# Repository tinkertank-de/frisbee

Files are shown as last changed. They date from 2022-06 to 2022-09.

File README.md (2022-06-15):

# Tinkertank's Frisbee - the sustainable Microcontroller

The Frisbee is your perfect tool to make new inventions out of e-waste, old toys and everyday objects.

front

The Frisbee is a microcontroller that can be plugged into any computer via USB and is recognized as a keyboard. Thus, similar to the Makey Makey ( https://makeymakey.com/ ), all conductive objects can be used to close circuits and trigger keystrokes. So a fork stuck in an apple becomes a space bar, or a high-five with your best friend becomes an arrow key.
If you still haven't had enough, you can turn the frisbee upside down to the dark side and dive deeper into the rabbit hole of makers and coders. On the backside and with the help of a block-based programming platform like OpenRoberta it is easy to run every actuator and sensor you find in the electronic waste to make your idea reality.

darkside
<br>*dark side of the ~~moon~~ frisbee*

# another microcontroller?

yes, why not.
it's plug and play like a [Makey Makey](https://makeymakey.com/), it's accessible with alligator clamps and easy to reprogram like the [Micro:bit](https://microbit.org//), it's cheap like an [Arduino Nano](https://store.arduino.cc/collections/most-popular/products/arduino-nano-every-with-headers) and it's capable of running micropython for super fast and compile-free programming.
Aaaaand it's got a super sweet RG-Bee-LED shining through the pcb for instant feedback. (reverse mounted neopixel LED)

# comparison sheet
| | Arduino Uno | Makey Makey | Micro:Bit | Calliope | Frisbee 2.0 |
| --- | --- | --- | --- | --- | --- |
| Image | | | | | |
| forked from | | Pro Micro /<br>Arduino Leonardo | | Micro:Bit | Raspberry Pi Pico |
| | | | | | |
| hardware connectors | jumper wires | alligator clips | alligator clips (limited) | alligator clips | alligator clips |
| cpu | ATmega328 (8-bit) | Atmel 32U4 | ARM Cortex-M0 (Nordic nRF51822) mit 32-Bit | ARM Cortex-M0 (Nordic nRF51822) mit 32-Bit | dual-core Arm Cortex-M0+ |
| native node based programming | NO | NO | YES | YES | YES |
| Bluetooth | NO | NO | YES | YES | NO |
| Wifi | NO | NO | NO | NO | NO |
| additional periphery | LED | LED | Lagesensor, Buttons, LED Matrix, Kompass, RGB-LED, Temperatur, Lautsprecher, Mikrofon | Lagesensor, Buttons, LED Matrix, Kompass, RGB-LED, Temperatur, Lautsprecher, Mikrofon | LED |
| plug and play input device | NO | YES | NO | NO | YES |
| made in | china | china | ? | ? | D |
| hareware cost | 23,50 € | 55,00 € | 29,00 € | 40,00 € | 15,00 € |

# fair trade & regional
We try to produce the frisbee boards as sustainable as possible and under fair working conditions in germany.
We are experimenting with different technologies like Paper-PCBs or printing with conductive paint on wood as an eco-friendly alternative to epoxy-based PCBs.

# open source
The Frisbee, like its core, the Pi Pico, is completely open source and can be further developed, modified and used by all users under the Creative Commons 4.0 license.

# about
Tinkertank is a stationary and mobile makerspace based in Ludwigsburg, Germany, empowering kids and adults to the creative use of technology.
www.tinkertank.de

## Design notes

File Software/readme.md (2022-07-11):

# 1. Install Circuitpython

- Plug in your Frisbee device while holding den **BOOTSEL** Button *(it should show up as RPI-RP2)*
- copy **"adafruit-circuitpython-raspberry_pi_pico-de_DE-7.3.1.uf2"** to your device
- wait until it restarts *(it should show up as CIRCUITPY)*

# 2. copy code

- copy **code.py** and **lib folder** onto CIRCUITPY *(replace code.py)*

# 3. Test code

- got to **[keyboard-test.space](https://keyboard-test.space/)** *(or similar)* to test all functions

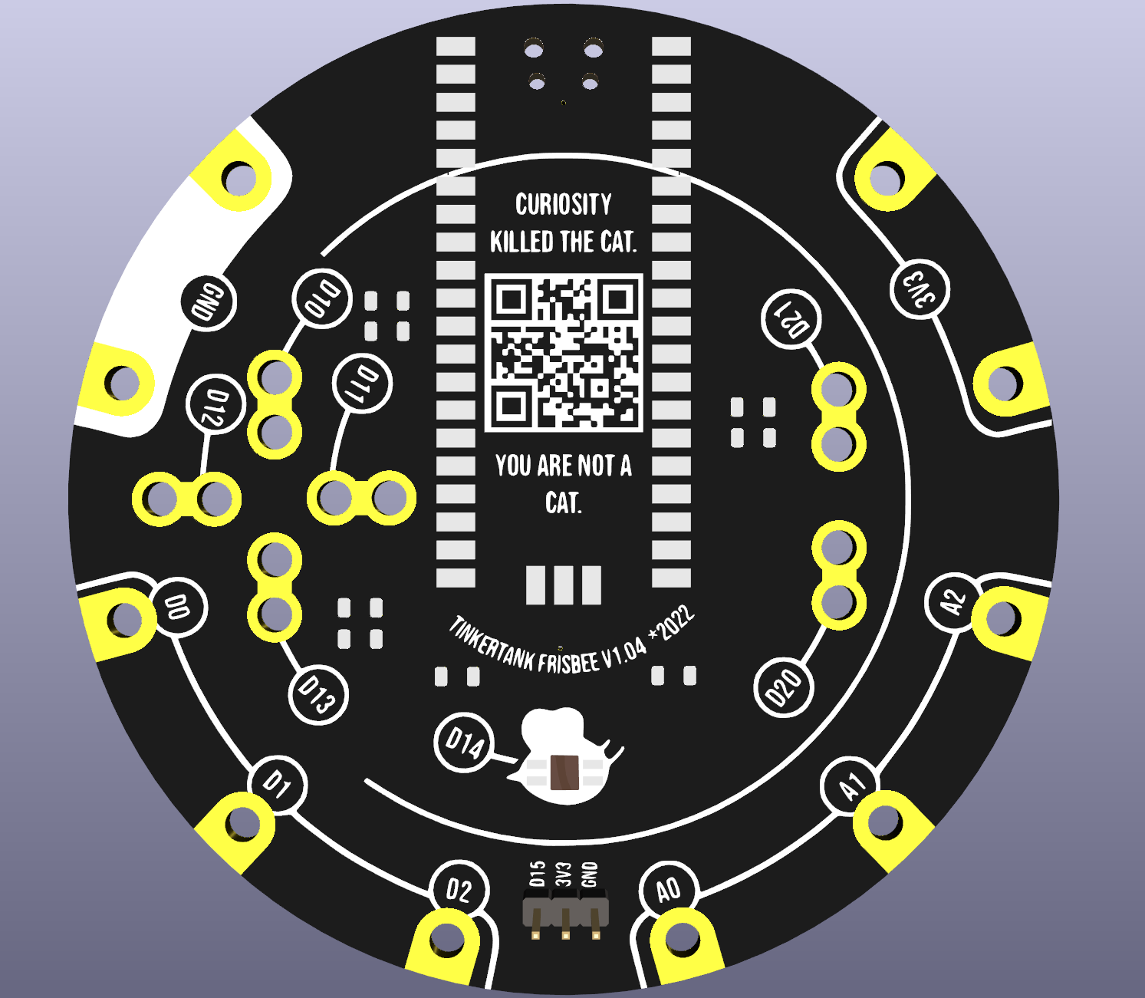
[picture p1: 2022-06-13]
Hardware/FrisBee/Screenshot from 2022-05-06 01-42-05.png

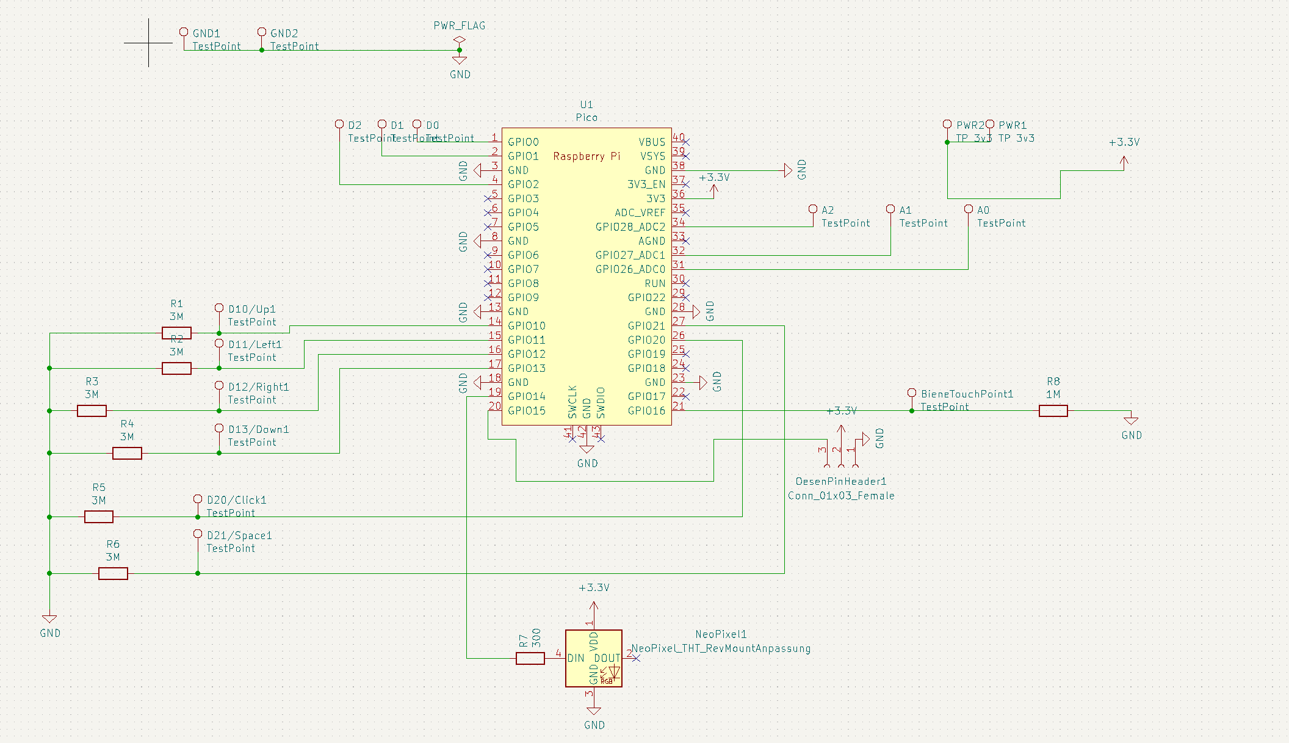
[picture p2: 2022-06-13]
Hardware/FrisBee/Schema.png

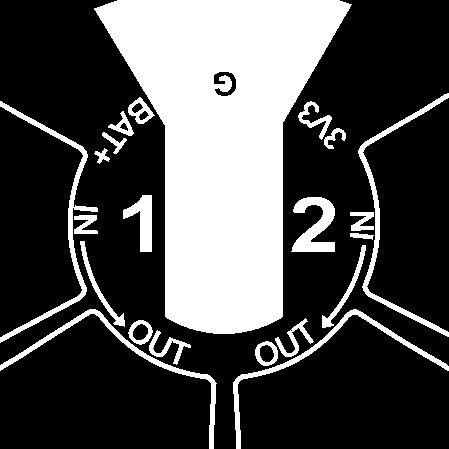
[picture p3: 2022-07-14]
Hardware/MotorBee/Silkscreen/motorbee-front.jpg

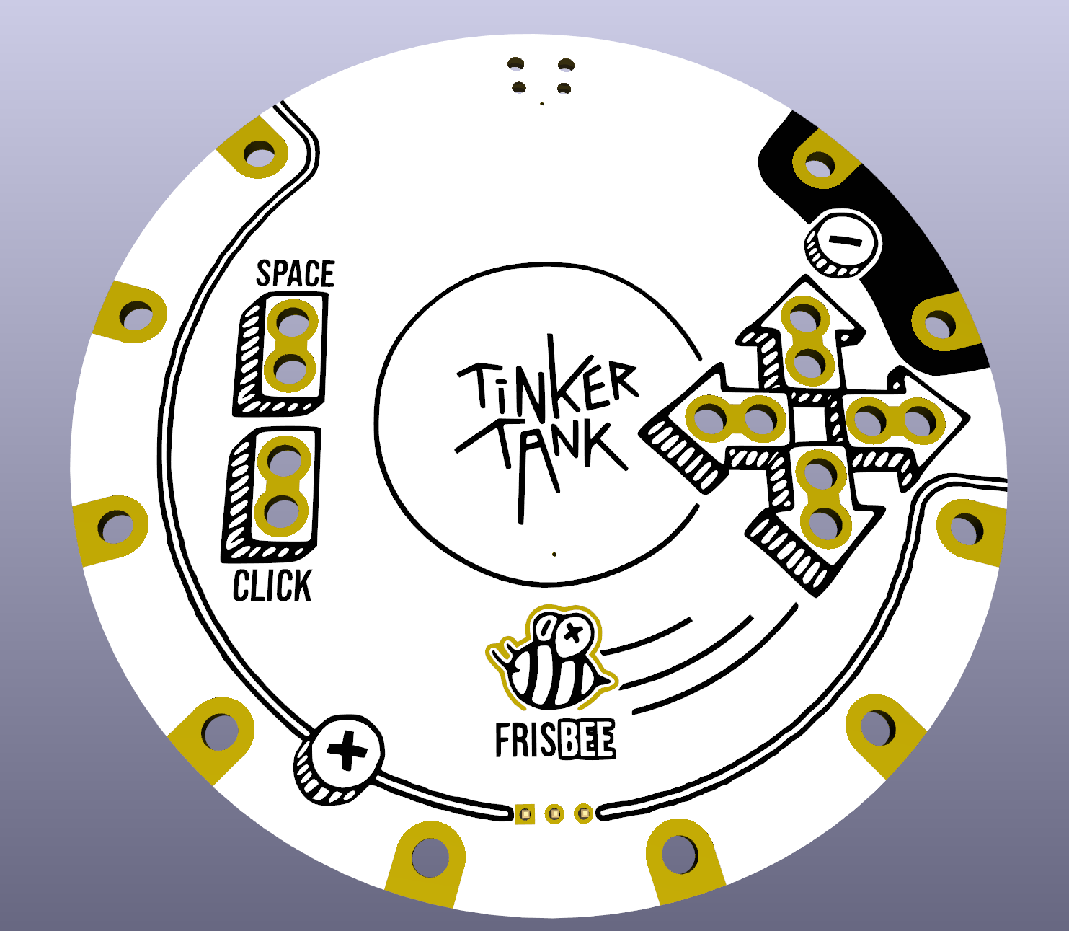
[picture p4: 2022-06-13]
Hardware/FrisBee/Screenshot from 2022-05-06 01-43-18.png

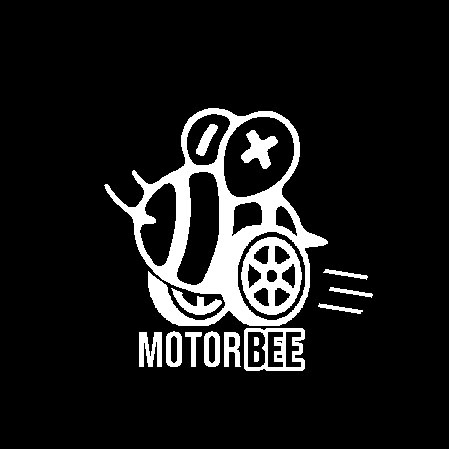
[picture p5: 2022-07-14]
Hardware/MotorBee/Silkscreen/motorbee_back.jpg

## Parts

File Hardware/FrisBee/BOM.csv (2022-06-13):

Id | Designator | Package | Quantity | Designation | Supplier and ref
1 | R1,R2,R3,R6,R5,R4 | R_1206_3216Metric | 6 | 3M
2 | R7 | R_1206_3216Metric | 1 | 300
3 | U1 | RPi_Pico_SMD_TH_meins | 1 | Pico
4 | R8 | R_1206_3216Metric | 1 | 1M

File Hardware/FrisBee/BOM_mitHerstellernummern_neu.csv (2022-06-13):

Id | Designator | Package | Quantity | Designation | Supplier and ref
1 | R1,R2,R3,R6,R5,R4 | R_1206_3216Metric | 6 | 3M | RMCF1206JT3M00
2 | R7 | R_1206_3216Metric | 1 | 300 | RMCF1206JT300R
3 | U1 | RPi_Pico_SMD_TH_meins | 1 | Pico | SC0915
4 | R8 | R_1206_3216Metric | 1 | 1M | RMCF1206JT1M00

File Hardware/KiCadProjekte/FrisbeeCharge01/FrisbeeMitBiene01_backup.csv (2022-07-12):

Id | Designator | Package | Quantity | Designation | Supplier and ref
1 | R1,R2,R3,R6,R5,R4 | R_1206_3216Metric_Pad1.30x1.75mm_HandSolder | 6 | 3M
2 | PWR1,PWR2 | Edgeconnector_SMD_version | 2 | TP 3v3
3 | GND1,GND2,D1,A1,A2,A0,D0,D2 | Edgeconnector_SMD_version | 8 | TestPoint
4 | D10/Up1,D12/Right1,D13/Down1,D21/Space1,D11/Left1,D22/Click1 | KrokoConnector | 6 | TestPoint
5 | R7 | R_1206_3216Metric_Pad1.30x1.75mm_HandSolder | 1 | 220
6 | LED1 | Reversegullwing_VLRE31R1S2GS08 | 1 | LED
7 | U1 | RPi_Pico_SMD_TH_meins | 1 | Pico

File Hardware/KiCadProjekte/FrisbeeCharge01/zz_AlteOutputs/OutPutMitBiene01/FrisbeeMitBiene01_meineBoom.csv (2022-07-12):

Id | Designator | Package | Quantity | Designation | Supplier and ref
1 | R1,R2,R3,R6,R5,R4 | R_1206_3216Metric_Pad1.30x1.75mm_HandSolder | 6 | 3M | RMCF1206JT3M00
2 | PWR1,PWR2 | Edgeconnector_SMD_version | 2 | TP 3v3
3 | GND1,GND2,D1,A1,A2,A0,D0,D2 | Edgeconnector_SMD_version | 8 | TestPoint
4 | D10/Up1,D12/Right1,D13/Down1,D21/Space1,D11/Left1,D22/Click1 | KrokoConnector | 6 | TestPoint
5 | R7 | R_1206_3216Metric_Pad1.30x1.75mm_HandSolder | 1 | 220 | RMCF1206JT220R
6 | LED1 | Reversegullwing_VLRE31R1S2GS08 | 1 | LED | VLRE31R1S2GS08
7 | U1 | RPi_Pico_SMD_TH_meins | 1 | Pico | SC0915

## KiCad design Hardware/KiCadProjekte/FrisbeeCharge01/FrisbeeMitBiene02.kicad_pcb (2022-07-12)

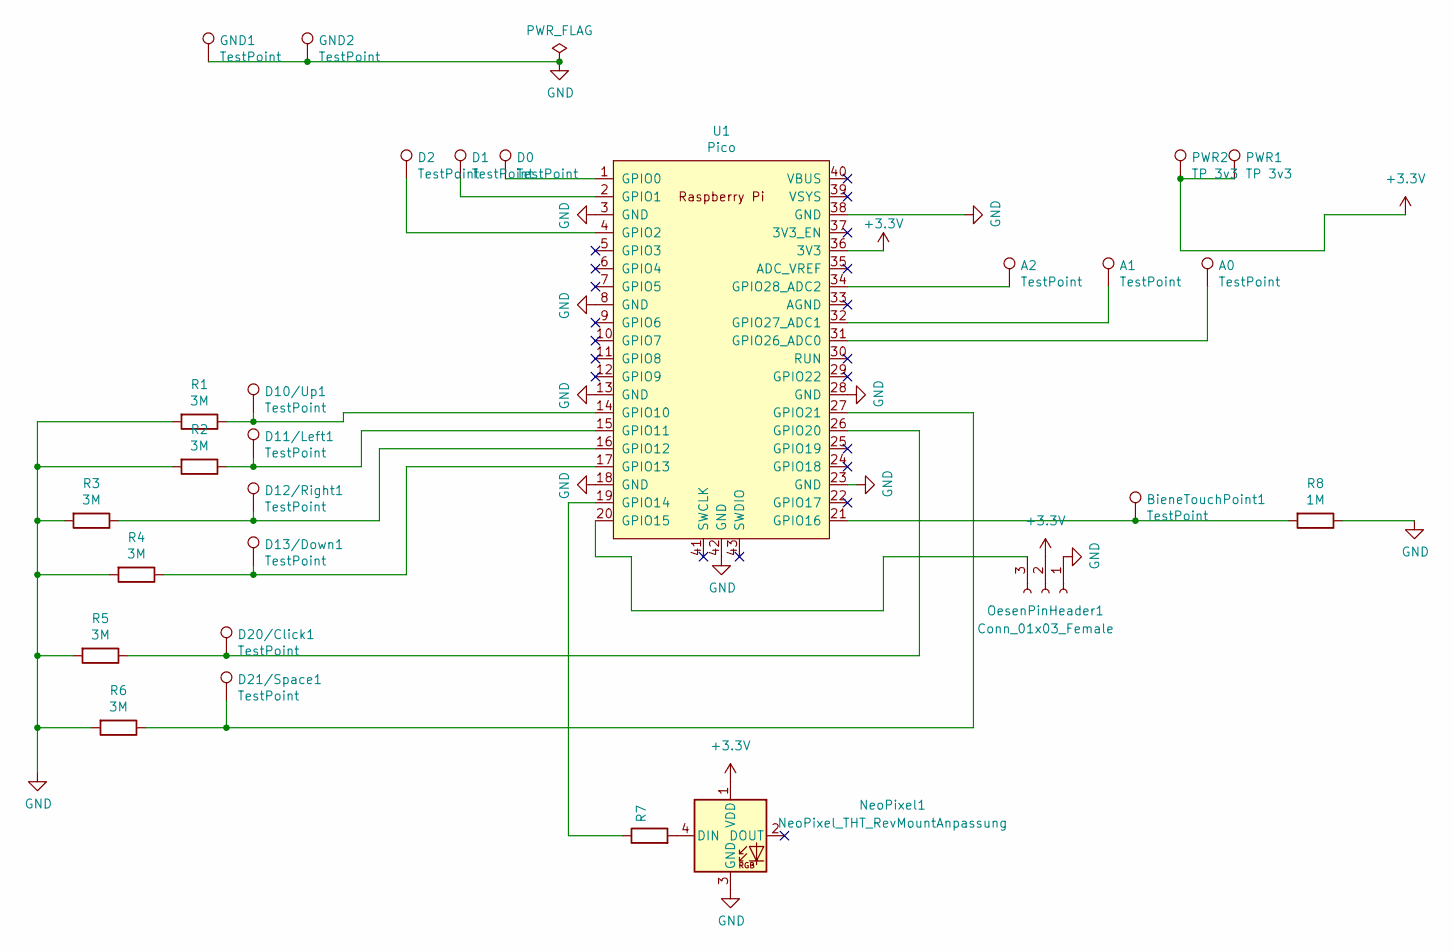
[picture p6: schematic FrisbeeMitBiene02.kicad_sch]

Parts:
A0, A1, A2: TestPoint; Edgeconnector_SMD_version
BieneTouchPoint1: TestPoint; testbiene
D0, D1, D2: TestPoint; Edgeconnector_SMD_version
D10/Up1, D11/Left1, D12/Right1, D13/Down1, D20/Click1, D21/Space1: TestPoint; KrokoConnector
GND1, GND2: TestPoint; Edgeconnector_SMD_version
NeoPixel1: NeoPixel_THT_RevMountAnpassung; NeoPixelReverseMountAnpassung
OesenPinHeader1: Conn_01x03_Female; PinHeader_1x03_P2.54mm_Vertical
PWR1, PWR2: TP 3v3; Edgeconnector_SMD_version
R1, R2, R3, R4, R5, R6: 3M
R7: (no value)
R8: 1M
U1: Pico; RPi_Pico_SMD_TH_meins

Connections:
+3V3: NeoPixel1.1 (VDD), OesenPinHeader1.2, PWR1.1, PWR2.1, U1.36 (3V3)
GND: GND1.1, GND2.1, NeoPixel1.3 (GND), OesenPinHeader1.1, R1.2, R2.2, R3.2, R4.2, R5.2, R6.2, R8.1, U1.3 (GND), U1.8 (GND), U1.13 (GND), U1.18 (GND), U1.23 (GND), U1.28 (GND), U1.38 (GND), U1.42 (GND)
unnamed: A0.1, U1.31 (GPIO26_ADC0)
unnamed: A1.1, U1.32 (GPIO27_ADC1)
unnamed: A2.1, U1.34 (GPIO28_ADC2)
unnamed: BieneTouchPoint1.1, R8.2, U1.21 (GPIO16)
unnamed: D0.1, U1.1 (GPIO0)
unnamed: D1.1, U1.2 (GPIO1)
unnamed: D2.1, U1.4 (GPIO2)
unnamed: D10/Up1.1, R1.1, U1.14 (GPIO10)
unnamed: D11/Left1.1, R2.1, U1.15 (GPIO11)
unnamed: D12/Right1.1, R3.1, U1.16 (GPIO12)
unnamed: D13/Down1.1, R4.1, U1.17 (GPIO13)
unnamed: D20/Click1.1, R5.1, U1.26 (GPIO20)
unnamed: D21/Space1.1, R6.1, U1.27 (GPIO21)
unnamed: NeoPixel1.4 (DIN), R7.2
unnamed: OesenPinHeader1.3, U1.20 (GPIO15)
unnamed: R7.1, U1.19 (GPIO14)

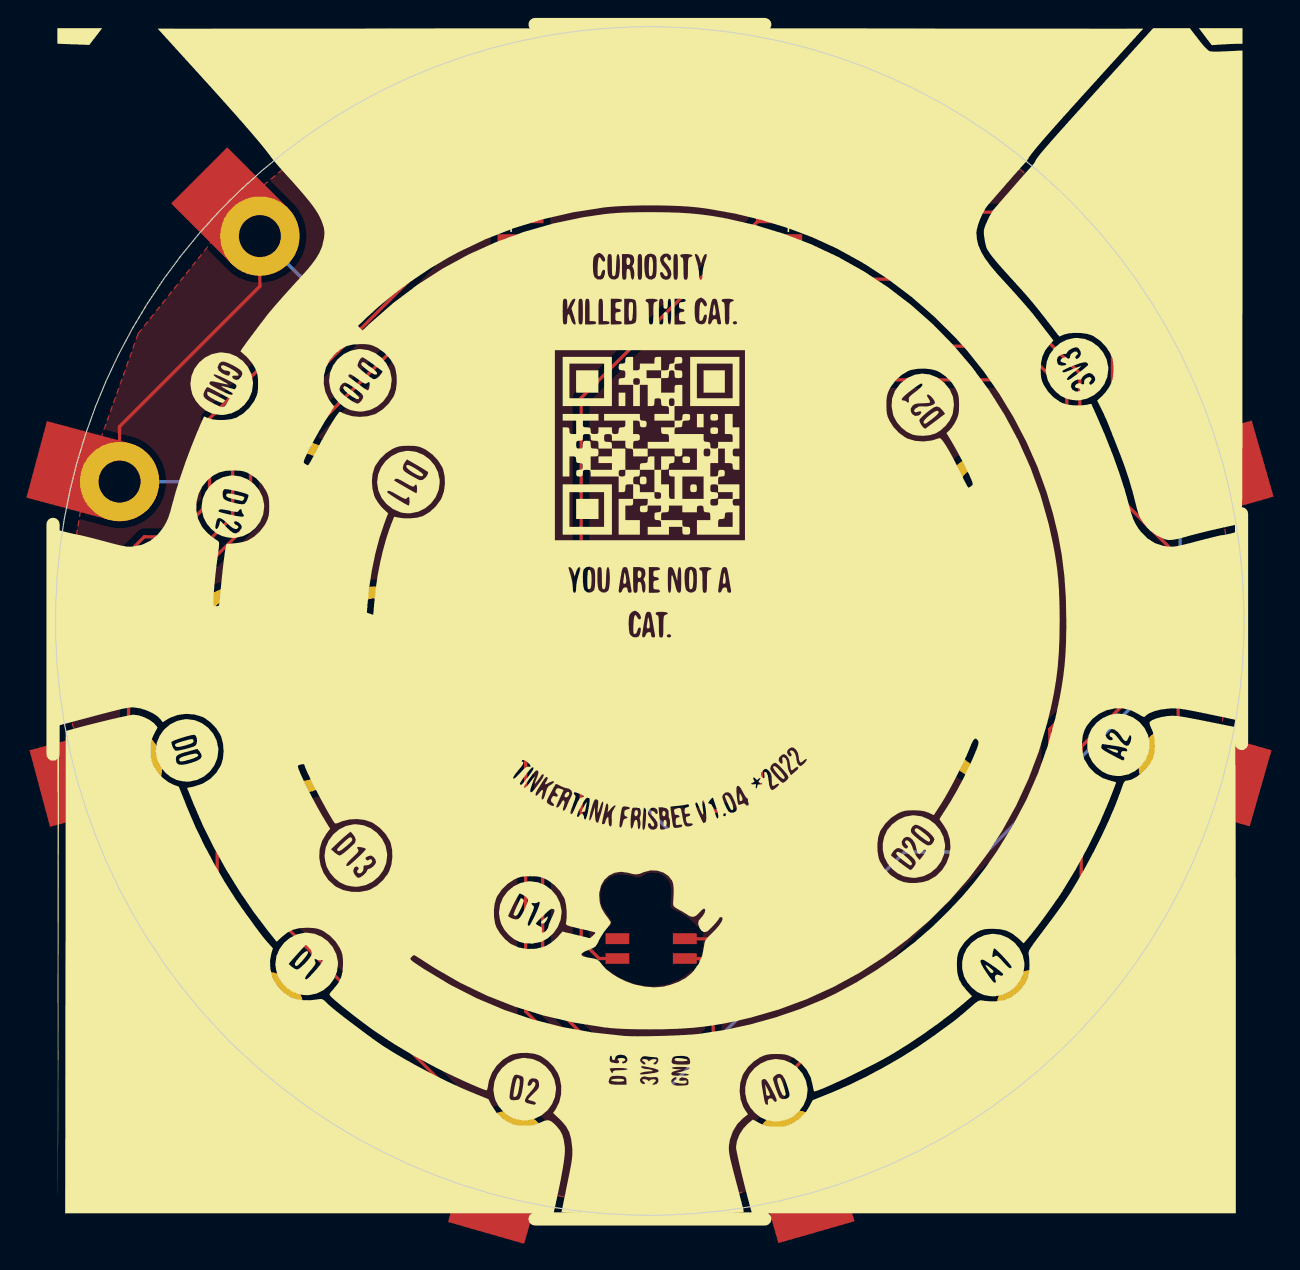
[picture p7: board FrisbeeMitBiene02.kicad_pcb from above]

Board: 2 copper layers, 90.0 x 90.0 mm, 28 parts (1 on the bottom side), 18 nets.

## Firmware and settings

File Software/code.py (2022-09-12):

## ---- TINKERTANK FRISBEE ---- ##
## ------ standard code ------- ##

## ---- Imports ---- ##
import time
import board
import digitalio
import touchio
import usb_hid
import neopixel
from adafruit_hid.keyboard import Keyboard
from adafruit_hid.keycode import Keycode
from adafruit_hid.mouse import Mouse

## ---- Definitions ---- ##

pinValueOld = [0,0,0,0,0,0] # previous pinValues
pinValue = [0,0,0,0,0,0]    # sum of pinValue Readings 
numReadings = 10			# number of readings before evaluating
threshold = 8    			# threshold to trigger key

RED = (255, 0, 0)
YELLOW = (255, 150, 0)
GREEN = (0, 255, 0)
BLUE = (0, 20, 255)
BLACK = (0,0,0)
pxColor = BLACK

Pin10= digitalio.DigitalInOut(board.GP10)
Pin10.direction=digitalio.Direction.INPUT

Pin11= digitalio.DigitalInOut(board.GP11)
Pin11.direction=digitalio.Direction.INPUT

Pin12= digitalio.DigitalInOut(board.GP12)
Pin12.direction=digitalio.Direction.INPUT

Pin13= digitalio.DigitalInOut(board.GP13)
Pin13.direction=digitalio.Direction.INPUT

Pin20= digitalio.DigitalInOut(board.GP20)
Pin20.direction=digitalio.Direction.INPUT

Pin21= digitalio.DigitalInOut(board.GP21)
Pin21.direction=digitalio.Direction.INPUT

pixels = neopixel.NeoPixel(board.GP14, 1, brightness=1, auto_write=False)



#touch
touch_pad = board.GP16
touch = touchio.TouchIn(touch_pad)

# all GPIOs to output high #

highPin0= digitalio.DigitalInOut(board.GP0)
highPin0.direction=digitalio.Direction.OUTPUT
highPin0.value = 1

highPin1= digitalio.DigitalInOut(board.GP1)
highPin1.direction=digitalio.Direction.OUTPUT
highPin1.value = 1

highPin2= digitalio.DigitalInOut(board.GP2)
highPin2.direction=digitalio.Direction.OUTPUT
highPin2.value = 1

highPin3= digitalio.DigitalInOut(board.GP26)
highPin3.direction=digitalio.Direction.OUTPUT
highPin3.value = 1

highPin4= digitalio.DigitalInOut(board.GP27)
highPin4.direction=digitalio.Direction.OUTPUT
highPin4.value = 1

highPin5= digitalio.DigitalInOut(board.GP28)
highPin5.direction=digitalio.Direction.OUTPUT
highPin5.value = 1

## startup animation
def startup(pc):
    for k in range(80):
        pixels[0] = (k,k*pc,0)
        time.sleep(0.01)
        pixels.show()
        
    pixels[0] = (10,10*pc,0)
    pixels.show()
    time.sleep(0.1)
    pixels[0] = (80,80*pc,0)
    pixels.show()
    time.sleep(0.1)
    pixels[0] = (20,20*pc,0)
    pixels.show()
    time.sleep(0.1)
    pixels[0] = (255,255*pc,0)
    pixels.show()
    time.sleep(1)
    for k in range(0, 255):
        pixels[0] = (255-k,(255-k)*pc,0)
        time.sleep(0.001)
        pixels.show()

try:
    keyboard_HID = Keyboard(usb_hid.devices)
    mouse_HID = Mouse(usb_hid.devices)
except:
    startup(0) #startup animation in yellow
else:
    startup(1) #startup animation in red



## functions ##

def sensePin(pin):    # digital Read pins and add to 'pinValue' variable
    global pinValue  
    if pin == 0:                      
        pinValue[0] += Pin10.value
    elif pin == 1:
        pinValue[1] += Pin11.value
    elif pin == 2:
        pinValue[2] += Pin12.value
    elif pin == 3:
        pinValue[3] += Pin13.value
    elif pin == 4:
        pinValue[4] += Pin20.value
    elif pin == 5:
        pinValue[5] += Pin21.value

def evaluatePins():             # evaluate 'pinValue'
    for i in range(6):
        global pinValue, pinValueOld, pxColor 
        
        # print (pinValue[i], end=" ")    	# print raw sum values for debugging
        if pinValue[i] > threshold:			# see if pinValue is higher than threshold
            pinValue[i] = 1
            if i < 4: pxColor = GREEN		#arrow keys: green
            elif i == 4: pxColor = RED
            elif i == 5: pxColor = BLUE
            
        else:
            pinValue[i] = 0 # not pressed
            
        if pinValueOld[i] < pinValue[i]:
            try:
                if i == 0: keyboard_HID.press(Keycode.UP_ARROW)
                elif i == 1: keyboard_HID.press(Keycode.LEFT_ARROW)
                elif i == 2: keyboard_HID.press(Keycode.RIGHT_ARROW)
                elif i == 3: keyboard_HID.press(Keycode.DOWN_ARROW)
                elif i == 4: mouse_HID.press(Mouse.LEFT_BUTTON)
                elif i == 5: keyboard_HID.press(Keycode.SPACEBAR)
            except:
                p = 0
            else:
                p = 0
        elif pinValueOld[i] > pinValue[i]:
            try:
                if i == 0: keyboard_HID.release(Keycode.UP_ARROW)
                elif i == 1: keyboard_HID.release(Keycode.LEFT_ARROW)
                elif i == 2: keyboard_HID.release(Keycode.RIGHT_ARROW)
                elif i == 3: keyboard_HID.release(Keycode.DOWN_ARROW)
                elif i == 4: mouse_HID.release(Mouse.LEFT_BUTTON)
                elif i == 5: keyboard_HID.release(Keycode.SPACEBAR)
            except:
                p = 0
            else:
                p = 0
        pinValueOld[i] = pinValue[i]		# save previous value
        pinValue[i] = 0   					# reset RawValue
    
def readTouchPoint():
    global touch, pxColor
    if touch.value:
        pxColor =(YELLOW)



## ---- Code ---- ##
while True:
    pxColor = BLACK
 
    for i in range(numReadings):	#read [10] times
        for j in range(6):	
            sensePin(j)		# read all 6 Pins
        time.sleep(0.002)

    evaluatePins()
    readTouchPoint()

    pixels[0] = pxColor
    pixels.show()
    
    # print('')   #for debugging

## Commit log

2022-06-13 initial code
    Initial code for the frisbee made in Playpiper ( https://make.playpiper.com/ )
    based on circuitpython firmware
2022-06-13 intitial code
    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
2022-07-01 prints rausgenommen
2022-07-04 derbe aufgeräumt.
    ein funktion für pin lesen, eine funktion für pins auswerten und tasten aktivieren
    statt ja eine funktion pro taste
2022-07-12 KicadProject Stand Charge01
    [BOM.csv, BOM_mitHerstellernummern_neu.csv, FrisbeeMitBiene01_backup.csv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]
2022-07-13 new file structure
    [BOM.csv, BOM_mitHerstellernummern_neu.csv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]
2022-07-14 motorbee mit rädern
